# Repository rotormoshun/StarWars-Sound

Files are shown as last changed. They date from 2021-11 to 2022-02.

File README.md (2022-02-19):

# star_wars_arcade_sound_pcb
The source files for the reproduction of the 1983 Star Sars Arcade sound PCB. The PCB is designed with Kicad. This project is complete and the PCB is verified working!

# Folder Structure
* bom - Bill of materials for the sound PCB
* gerbers -The gerber files for the sound PCB
* images - Images used in the development on the sound PCB 
* pcb - The Kicad design files for the sound PCB

# PCB Specifications
* Layers: 2
* Dimensions: 293mm X 227mm
* Different PCB Design: 1
* PCB Thickness: 1.6mm
* Surface Finish: HASL
* Castellated Holes: No
* Copper Weight: 1oz.

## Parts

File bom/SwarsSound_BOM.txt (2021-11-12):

Part_ID                                                 QTY     DESC            Part_Num

C1,  C2,  C3,  C4,  C5,  C6,  C7,  C8,  C9,  C10,       41      0.1uf           Digikey 399-4454-1-ND
C11, C12, C16, C17, C18, C19, C20, C22, C23, C24,
C25, C26, C27, C28, C30, C37, C38, C40, C41, C42,
C43, C45, C54, C55, C59, C60, C61, C31, C32, C34,
C36

C46, C48, C49, C50, C56, C57, C58                       7       0.0027uf        Digikey 478-11573-1-ND
C13, C14, C15, C47, C53		                            5       100uf 50V       Digikey 1572-1309-ND
C29, C33, C35, C39                                      4       1000pf          Digikey 1216PHCT-ND
C44                                                     1       0.01uf          Digikey 399-4452-1-ND
C51                                                     1       0.47uf          Digikey 1572-1461-ND‎
C52                                                     1       10uf            Digikey 1572-1294-ND

DS1                                                     1       BLUE LED        Digikey VAOL-5701SBY4-ND

P2                                                      1       7 pin con       Digikey A19878-ND‎

Q1, Q2                                                  2       2N3906          Digikey 2N3906TAFSCT-ND
Q3, Q4                                                  2       2N3904          Digikey 2N3904TAFSCT-ND

R1,  R4,  R7,  R12, R15, R20, R22, R24, R26             9       1K              Digikey 1.0KQBK-ND
R2,  R3,  R5,  R6,  R10, R13, R17, R37                  8       10K             Digikey 10KQBK-ND
R30, R39, R40, R42, R46, R47                            6       12K             Digikey 12KQBK-ND
R21, R23, R50, R54, R55                                 5       47K             Digikey 47KQBK-ND
R48, R49, R52, R53                                      4       22K             Digikey 22KQBK-ND
R35, R51, R56                                           3       2.2K            Digikey 2.2KQBK-ND
R8,  R9,  R44                                           3       100             Digikey 100QBK-ND
R11, R14, R16                                           3       3.3K            Digikey 3.3KQBK-ND
R25, R27                                                2       82K             Digikey 82KQBK-ND
R33, R34                                                2       4.7K            Digikey 4.7KQBK-ND
R31, R32                                                2       560K            Digikey 560KQBK-ND
R18                                                     1       1.8K            Digikey 1.8KQBK-ND
R19, R28                                                2       100K            Digikey 100KQBK-ND
R29                                                     1       15K             Digikey 15KQBK-ND
R36                                                     1       15              Digikey 15QBK-ND
R38                                                     1       470             Digikey 470QBK-ND
R41                                                     1       68K             Digikey 68KQBK-ND
R43                                                     1       1.5K            Digikey 1.5KQBK-ND
R45                                                     1       470K            Digikey 470KQBK-ND

TP1,  TP2, TP3, TP4, TP5, TP6, TP7, TP8, TP9, TP10      12      Test Point      Digikey WM6456-ND
TP11, TP12

D-2, D-3, D-4, D-5                                      4       POKEY           Ebay
B-2, C-3, C-4                                           3       TL084           Digikey 296-1782-5-ND‎
H-1, J/K-1                                              2       2764            Jameco 2303119
F-3, F-5                                                2       LS161           Digikey 296-1646-5-ND
J-2, J-3                                                2       LS139           Digikey 296-1640-5-ND
J-5, K-5                                                2       LS374           Jameco 47634
C/D-1                                                   1       TMS-5220        Ebay
F/H-1                                                   1       6116-2K-RAM     Jameco 242675
F/H-5                                                   1       LS125           Jameco 46501
E-1                                                     1       PIA             Ebay
F-2                                                     1       CD4069/74C04    Jameco 13231
A-3                                                     1       NE556           Jameco 904114
B-3                                                     1       R5106           Ebay
H-2                                                     1       LS04            Jameco 46316
H-3                                                     1       LS00            Jameco 46252
H-5                                                     1       LS74            Jameco 48004
K-3                                                     1       6809E           Ebay

IC Sockets
-------------------
8  pin     1
14 pin     9
16-pin     4
20-pin     2
24-pin     1
28-pin     3
40-pin     6

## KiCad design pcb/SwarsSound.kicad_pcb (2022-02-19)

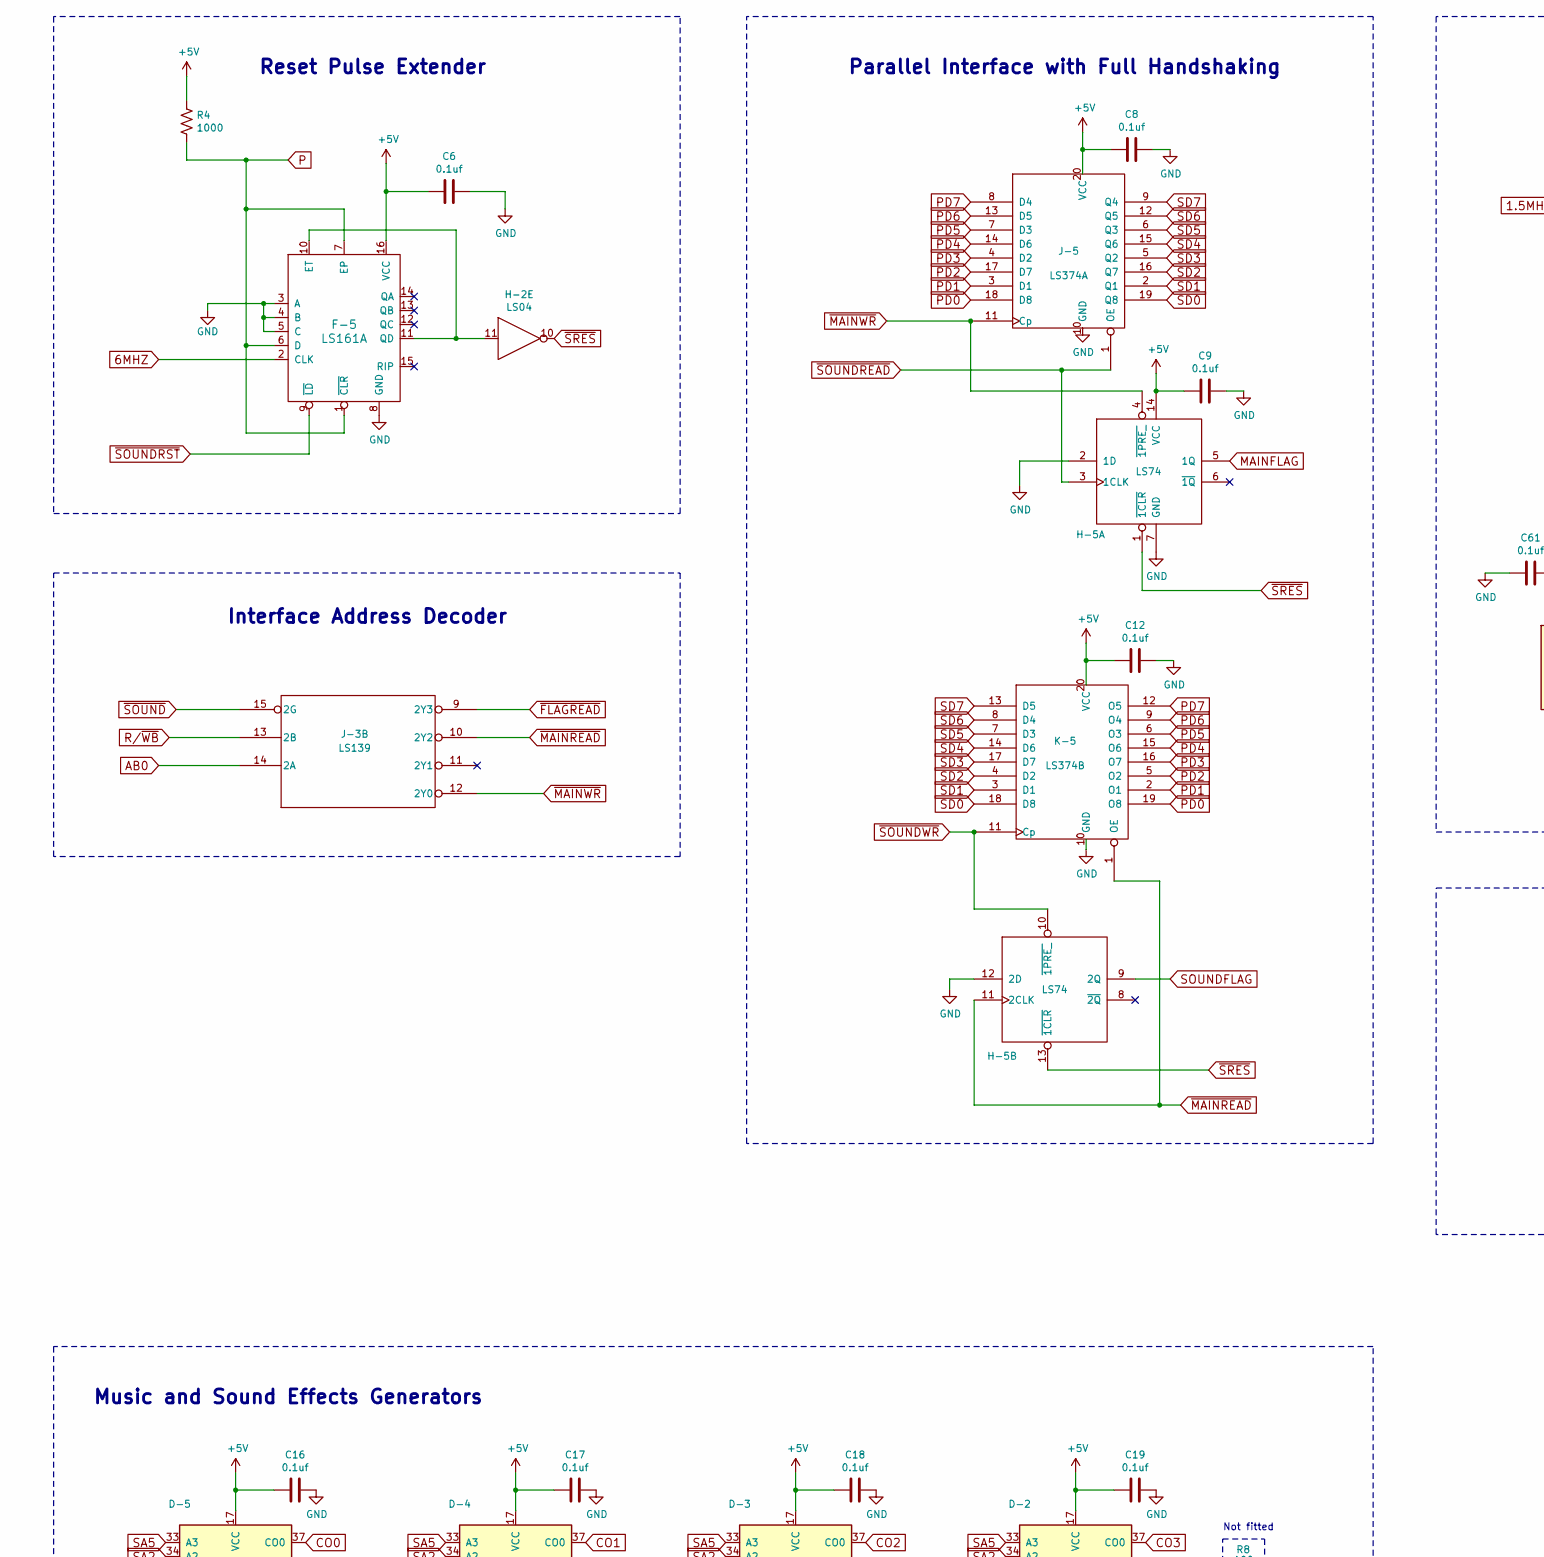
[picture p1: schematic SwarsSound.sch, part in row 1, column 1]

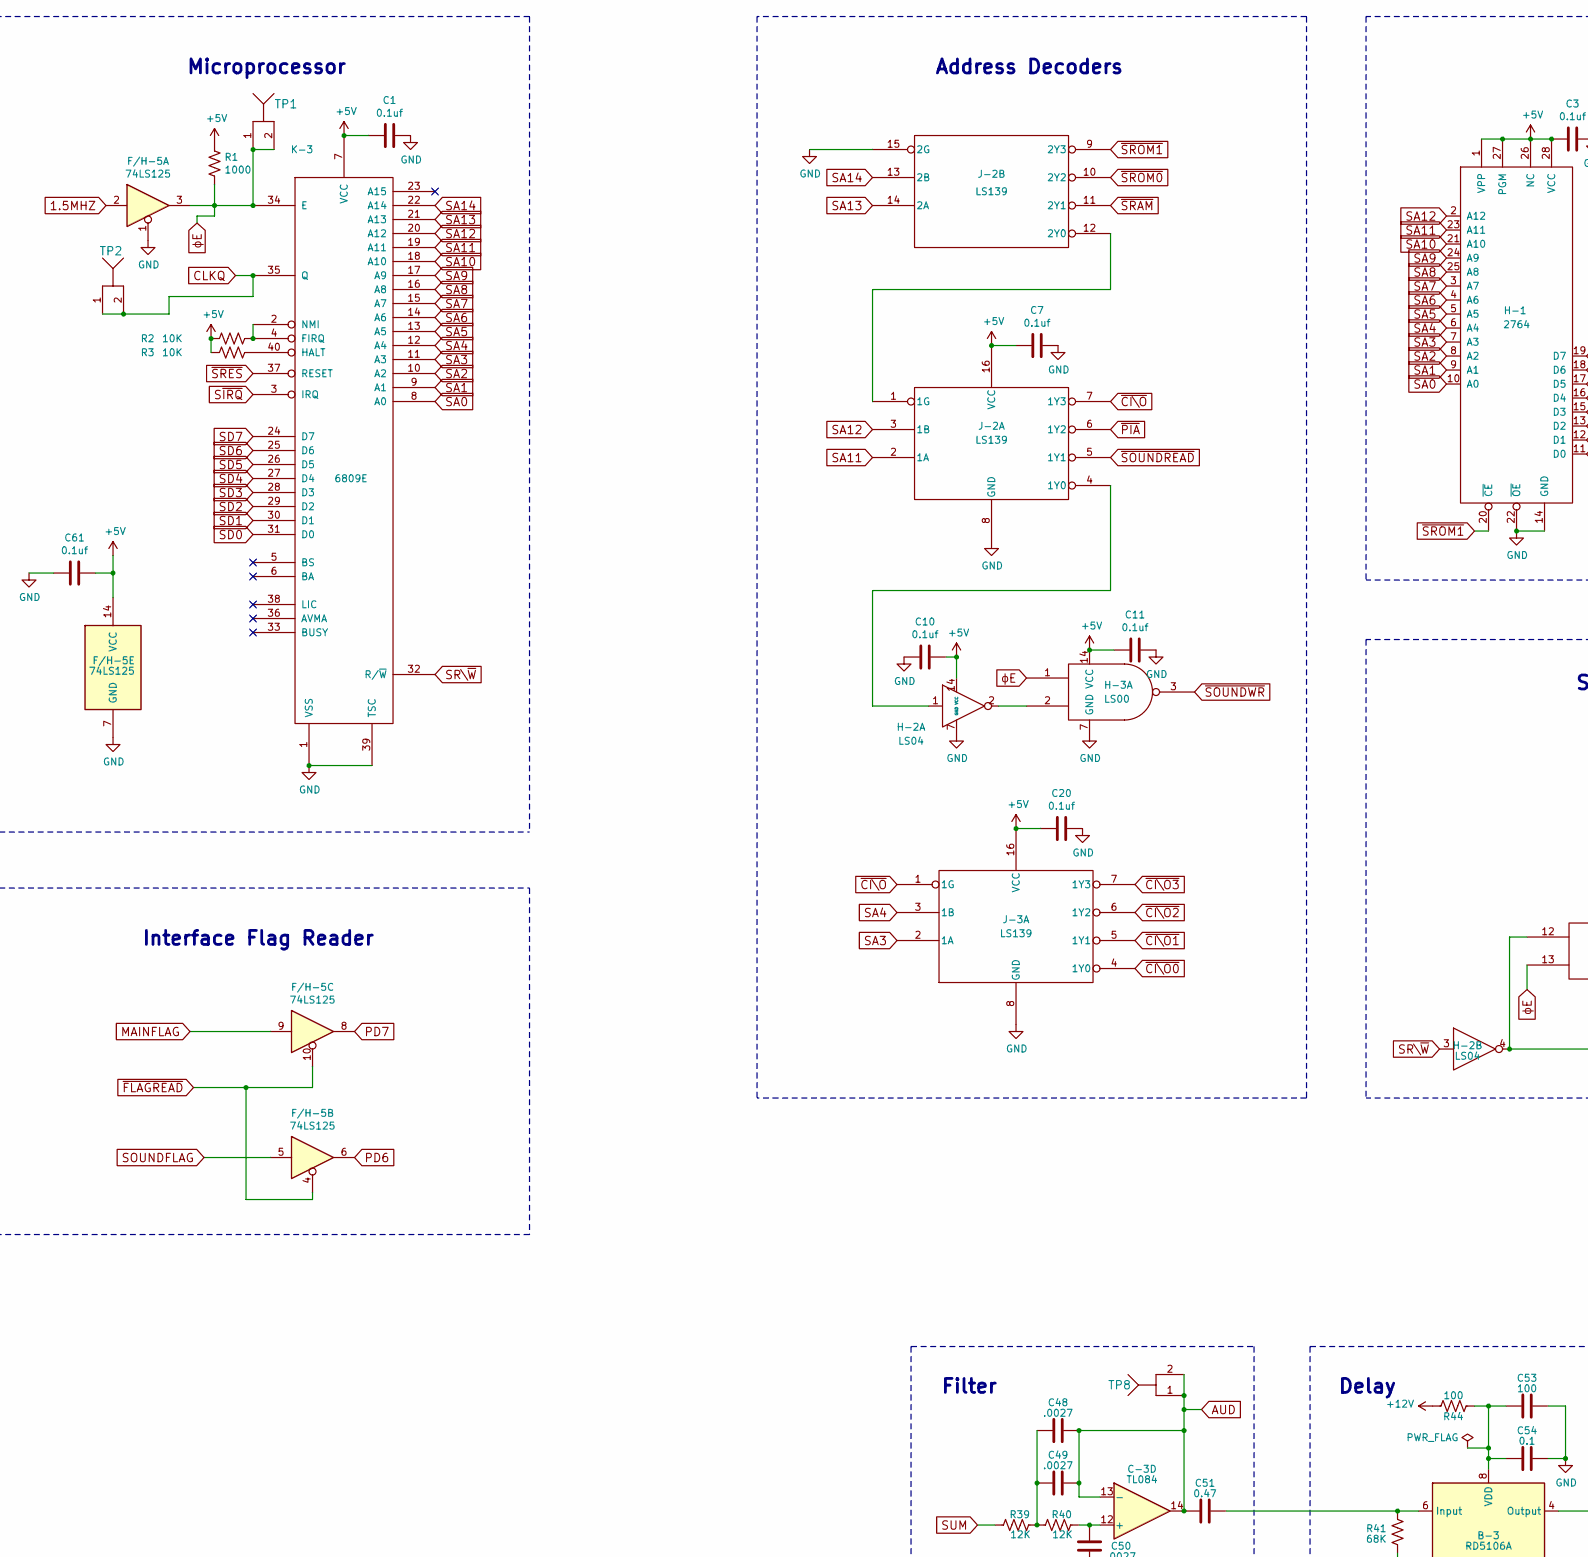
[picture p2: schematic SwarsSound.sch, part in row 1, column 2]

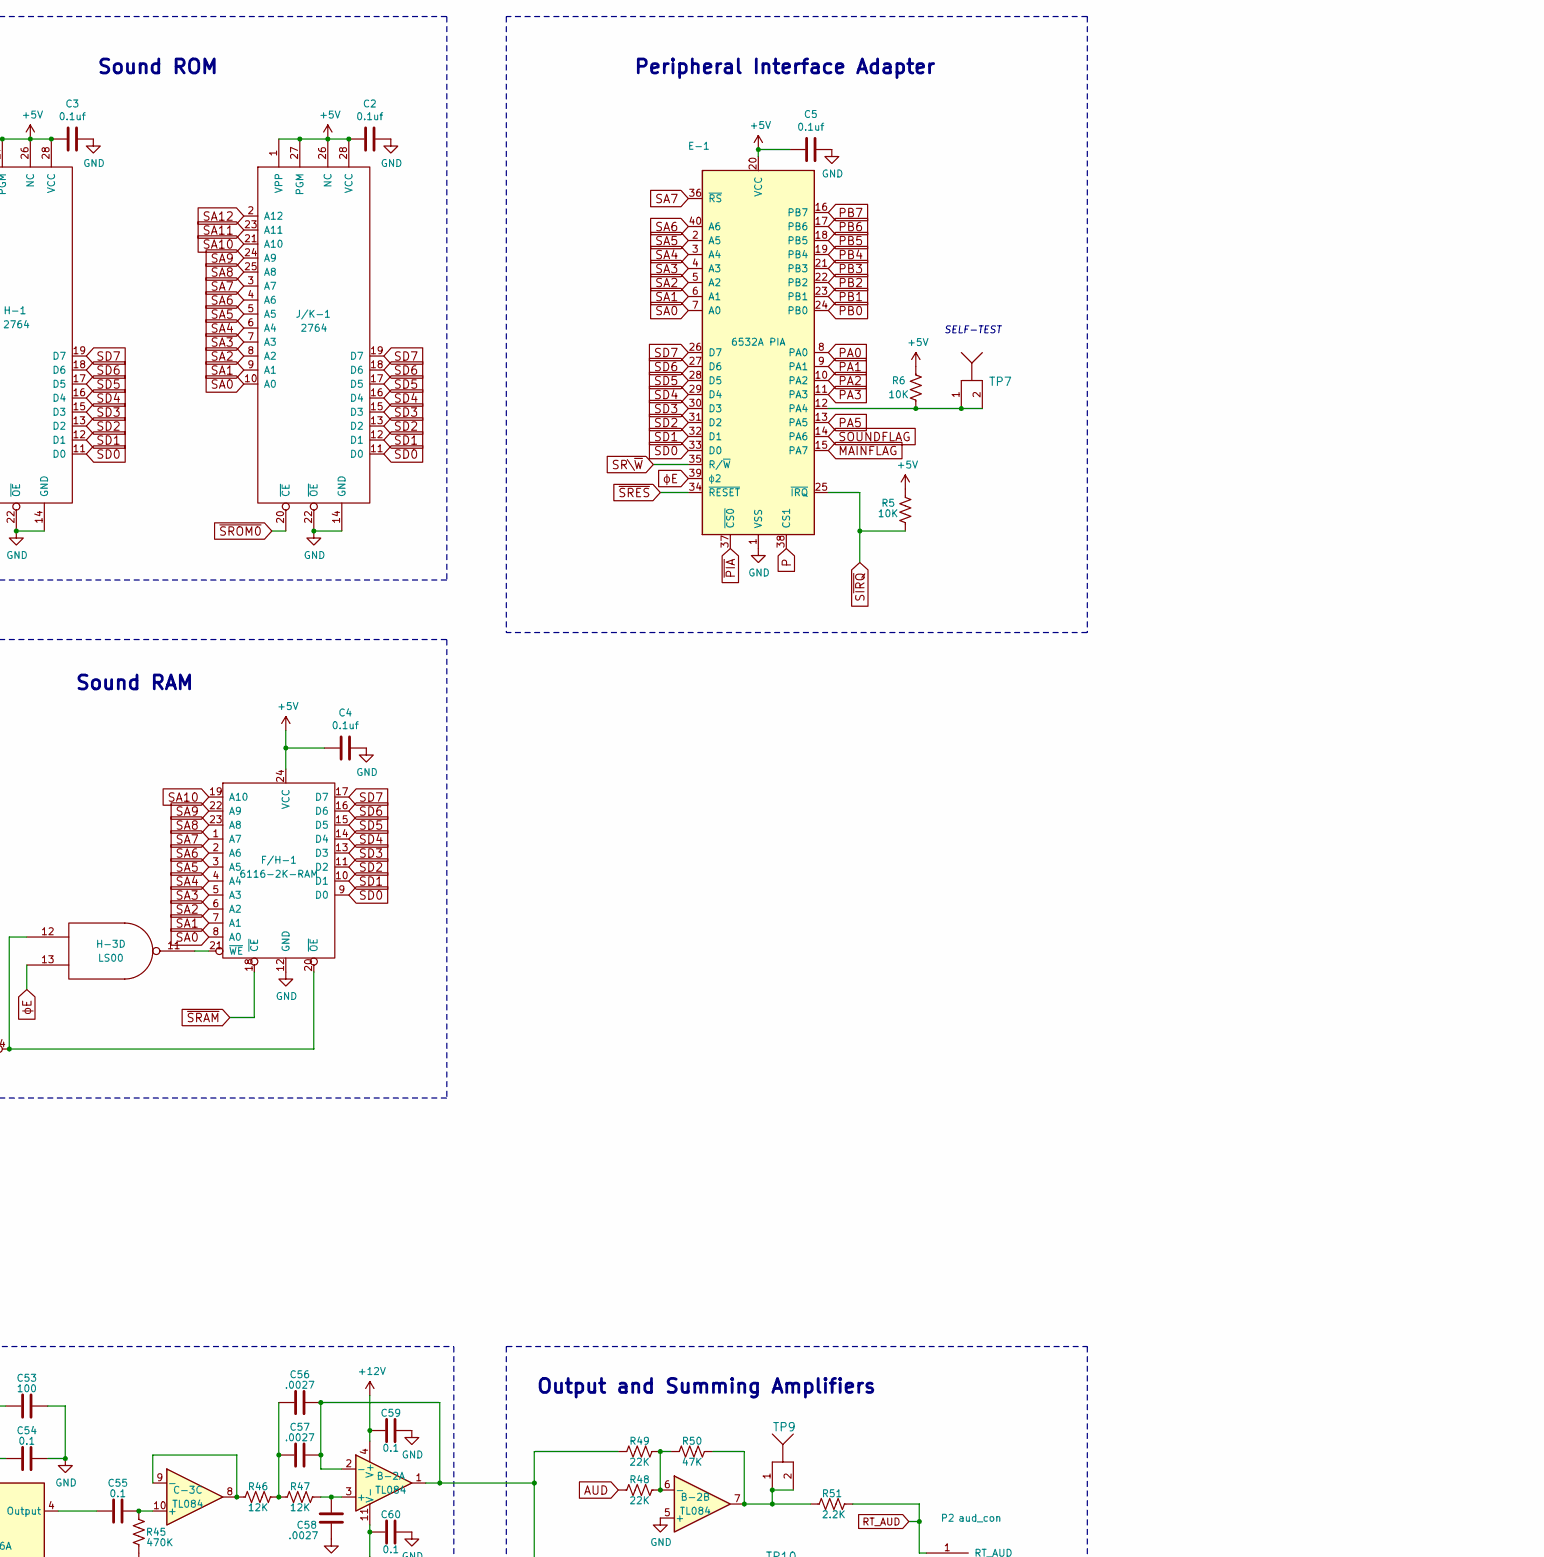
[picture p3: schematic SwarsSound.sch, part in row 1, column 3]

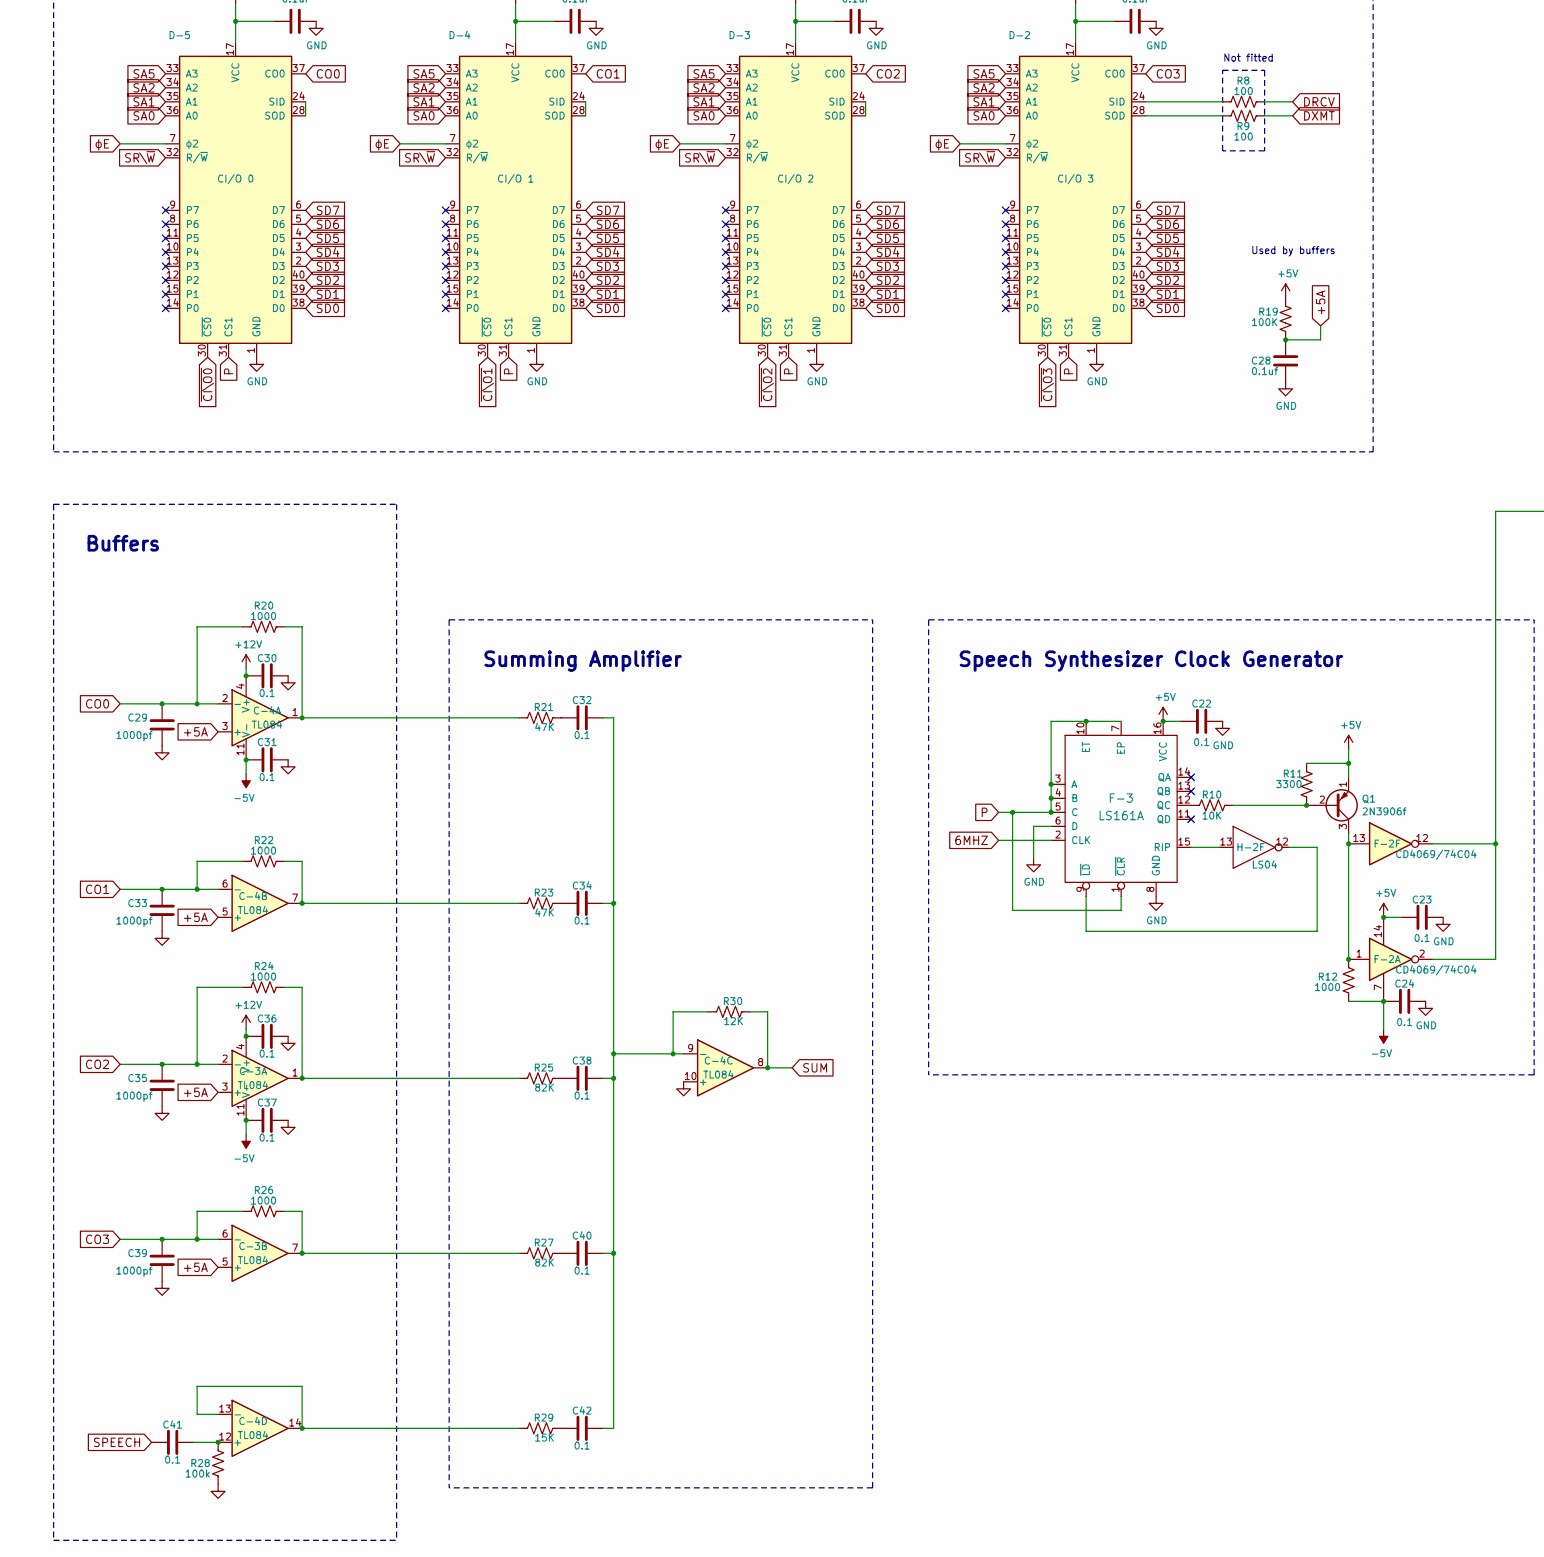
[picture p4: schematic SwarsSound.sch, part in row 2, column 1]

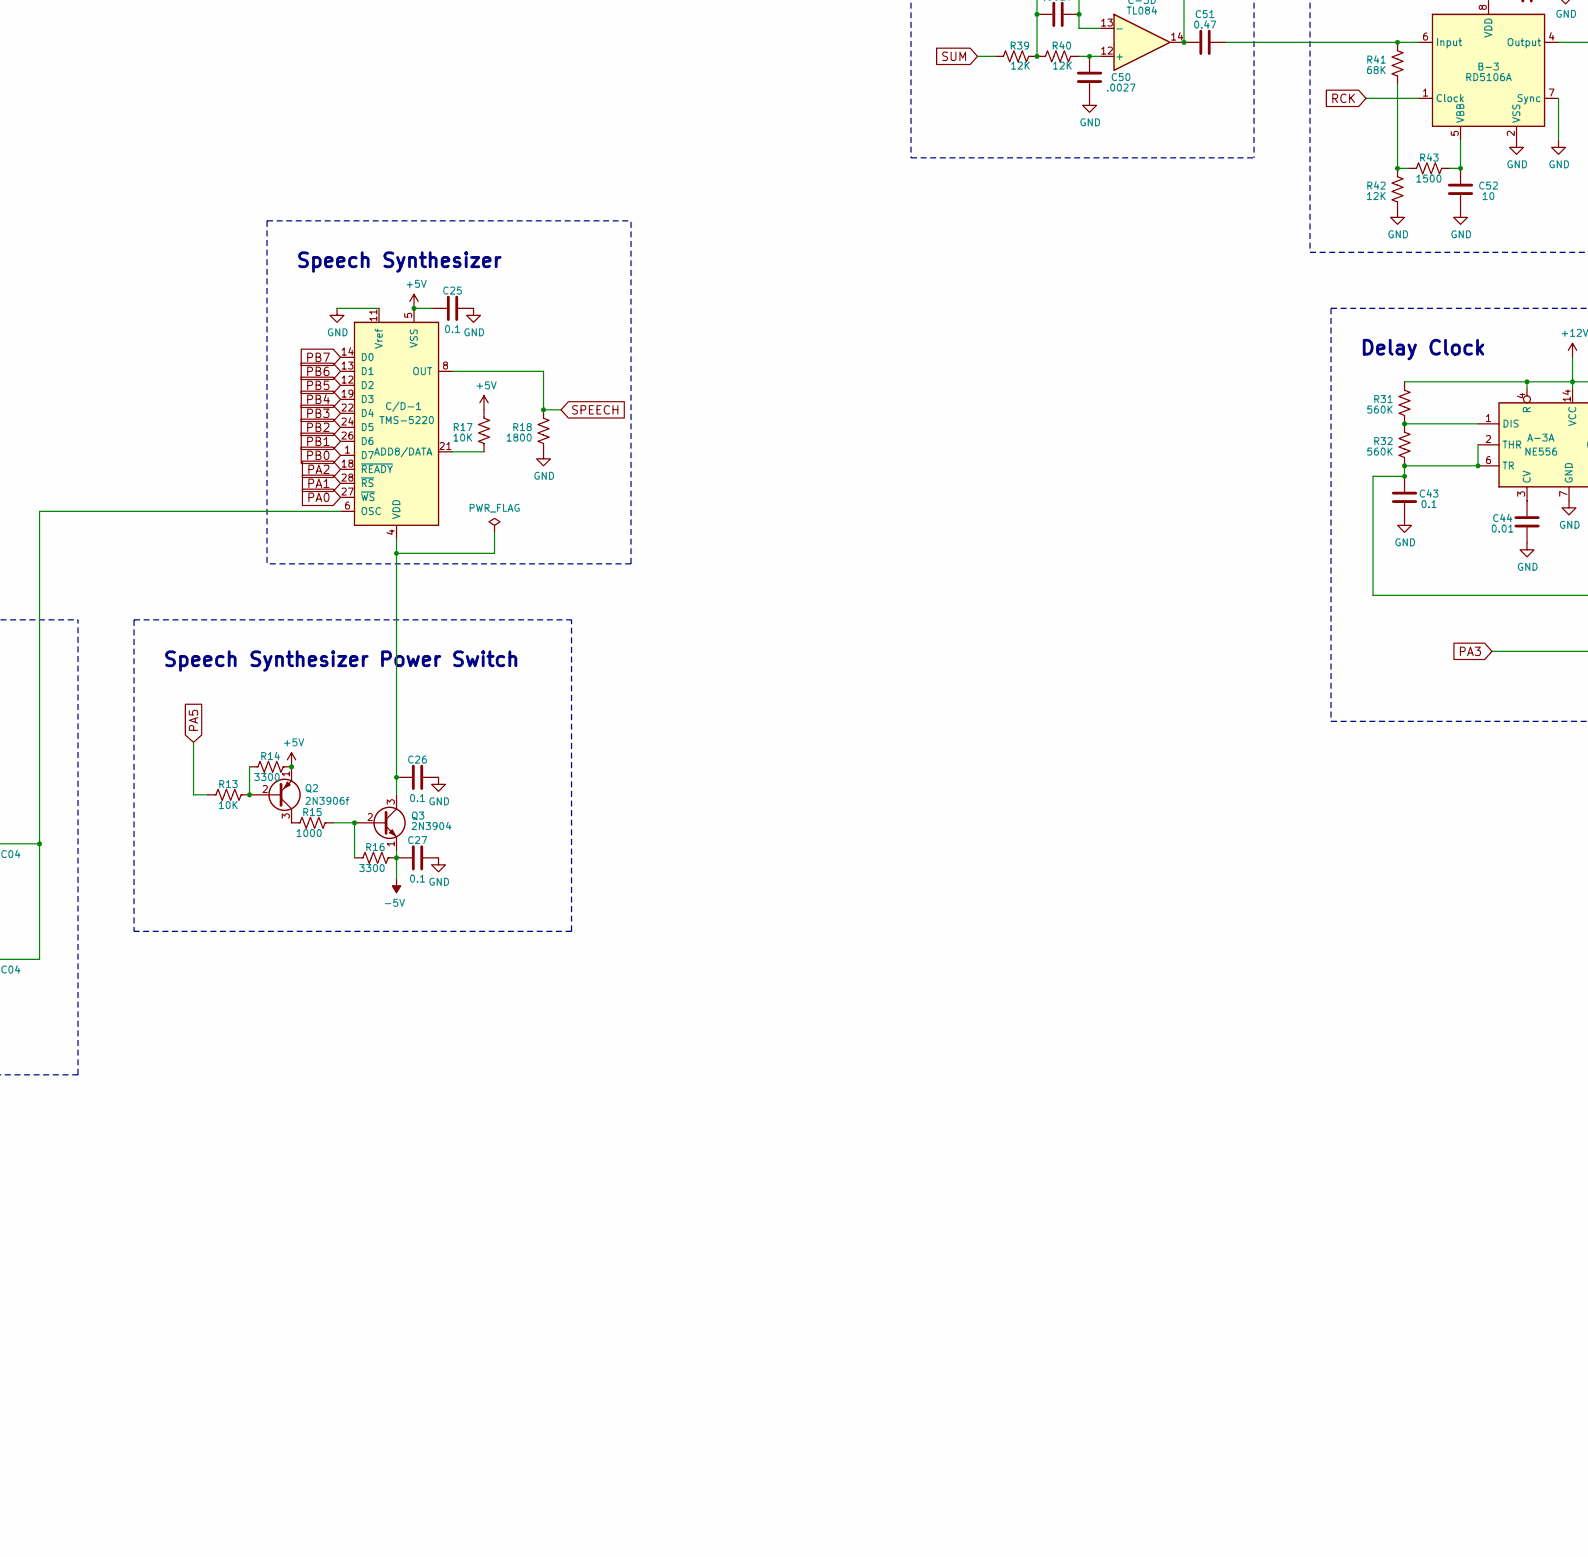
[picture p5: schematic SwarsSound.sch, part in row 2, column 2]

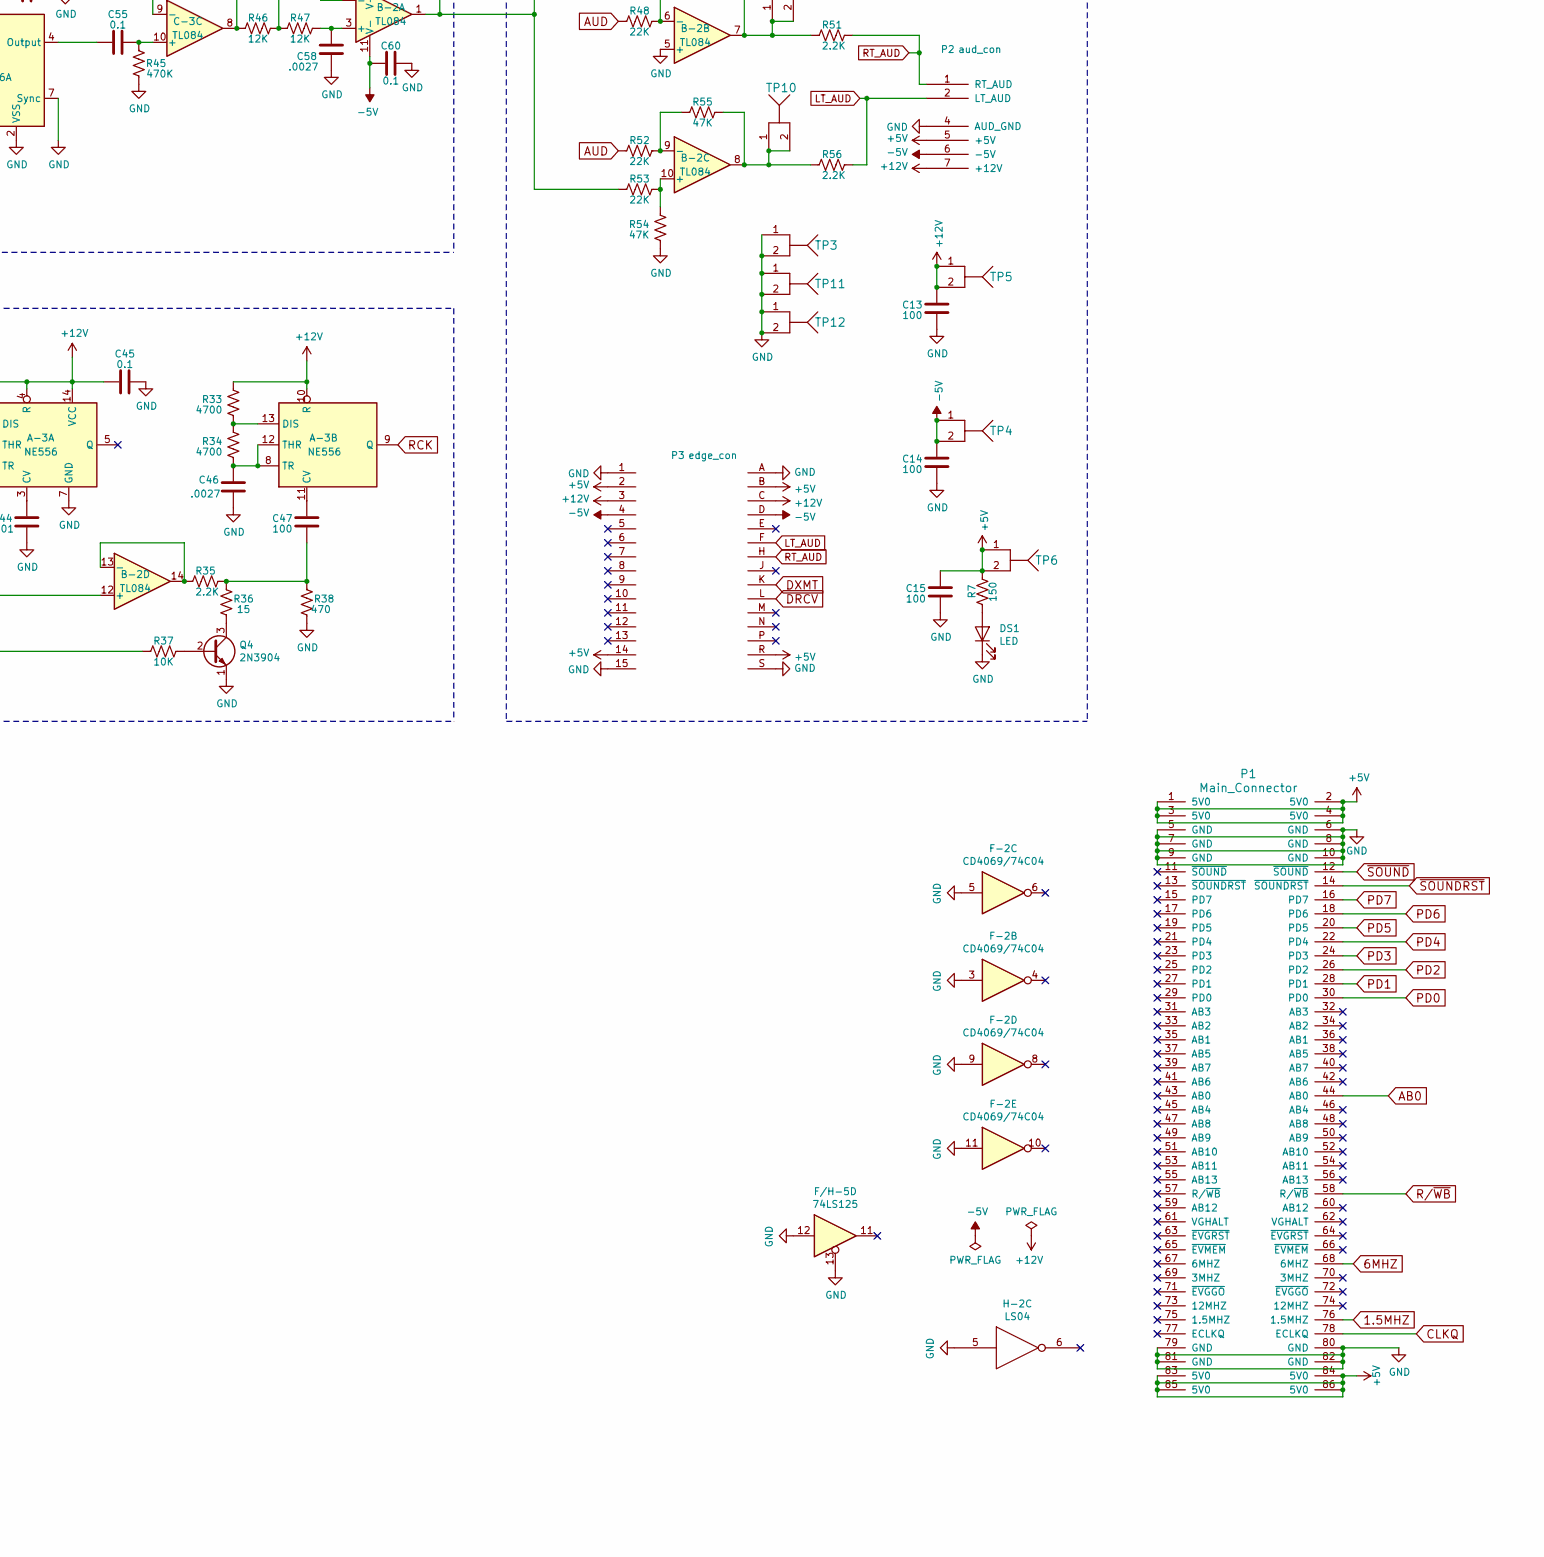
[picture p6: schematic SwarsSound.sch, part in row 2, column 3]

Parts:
A-3: NE556; DIP14
B-2: TL084; DIP14
B-3: RD5106A; DIP8
C1, C2, C3, C4, C5, C6, C7, C8, C9, C10, C11, C12, C16, C17, C18, C19, C20, C28, C61: 0.1uf; GenericComp
C13, C14: 100; CapElec3
C15, C47, C53: 100; CapElec2
C22, C23, C24, C25, C26, C27, C30, C31, C32, C34, C36, C37, C38, C40, C41, C42, C43, C45, C54, C55, C59, C60: 0.1; GenericComp
C29, C33, C35, C39: 1000pf; GenericComp
C44: 0.01; GenericComp
C46, C48, C49, C50, C56, C57, C58: .0027; GenericComp
C51: 0.47; CapElec2
C52: 10; CapElec2
C-3, C-4: TL084; DIP14
C/D-1: TMS-5220; DIP28
D-2: CI/O 3; DDIP40
D-3: CI/O 2; DDIP40
D-4: CI/O 1; DDIP40
D-5: CI/O 0; DDIP40
DS1: LED
E-1: 6532A PIA; DDIP40
F-2: CD4069/74C04; DIP14
F-3, F-5: LS161A; DIP16
F/H-1: 6116-2K-RAM; DDIP24
F/H-5: 74LS125; DIP14
H-1: 2764; DIP28
H-2: LS04; DIP14
H-3: LS00; DIP14
H-5: LS74; DIP14
J-2, J-3: LS139; DIP16
J-5: LS374A; DIP20
J/K-1: 2764; DIP28
K-3: 6809E; DDIP40
K-5: LS374B; DIP20
P1: Main_Connector; J17
P2: aud_con; Aud_Con_7
P3: edge_con; J20
Q1, Q2: 2N3906f; GenericTrans
Q3, Q4: 2N3904; GenericTrans
R1, R4, R12, R15, R20, R22, R24, R26: 1000; GenericComp
R2, R3, R5, R6, R10, R13, R17, R37: 10K; GenericComp
R7: 150; GenericComp
R8, R9, R44: 100; GenericComp
R11, R14, R16: 3300; GenericComp
R18: 1800; GenericComp
R19: 100K; GenericComp
R21, R23, R50, R54, R55: 47K; GenericComp
R25, R27: 82K; GenericComp
R28: 100k; GenericComp
R29: 15K; GenericComp
R30, R39, R40, R42, R46, R47: 12K; GenericComp
R31, R32: 560K; GenericComp
R33, R34: 4700; GenericComp
R35, R51, R56: 2.2K; GenericComp
R36: 15; GenericComp
R38: 470; GenericComp
R41: 68K; GenericComp
R43: 1500; GenericComp
R45: 470K; GenericComp
R48, R49, R52, R53: 22K; GenericComp
TP1, TP2, TP3, TP4, TP5, TP6, TP7, TP8, TP9, TP10, TP11, TP12: TP; TEST_POINT

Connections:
1.5MHZ: F/H-5.2, P1.76 (1.5MHZ)
6MHZ: F-3.2 (CLK), F-5.2 (CLK), P1.68 (6MHZ)
+5A: C28.2, C-3.3 (+), C-3.5 (+), C-4.3 (+), C-4.5 (+), R19.2
+5V: C1.2, C2.2, C3.2, C4.2, C5.2, C6.2, C7.2, C8.2, C9.2, C10.1, C11.2, C12.2, C15.2, C16.2, C17.2, C18.2, C19.2, C20.2, C22.1, C23.1, C25.1, C61.1, C/D-1.5 (VSS), D-2.17 (VCC), D-3.17 (VCC), D-4.17 (VCC), D-5.17 (VCC), E-1.20 (VCC), F-2.14, F-3.16 (VCC), F-5.16 (VCC), F/H-1.24 (VCC), F/H-5.14 (VCC), H-1.1 (VPP), H-1.26 (NC), H-1.27 (PGM), H-1.28 (VCC), H-2.14 (VCC), H-3.14 (VCC), H-5.14 (VCC), J-2.16 (VCC), J-3.16 (VCC), J-5.20 (VCC), J/K-1.1 (VPP), J/K-1.26 (NC), J/K-1.27 (PGM), J/K-1.28 (VCC), K-3.7 (VCC), K-5.20 (VCC), P1.1 (5V0), P1.2 (5V0), P1.3 (5V0), P1.4 (5V0), P1.83 (5V0), P1.84 (5V0), P1.85 (5V0), P1.86 (5V0), P2.5 (+5V), P3.2, P3.14, P3.B, P3.R, Q1.1, Q2.1, R1.1, R2.1, R3.1, R4.1, R5.1, R6.1, R7.1, R11.1, R14.2, R17.2, R19.1, TP6.1, TP6.2
+12V: A-3.4 (R), A-3.10 (R), A-3.14 (VCC), B-2.4 (V+), C13.2, C30.1, C36.1, C45.1, C59.1, C-3.4 (V+), C-4.4 (V+), P2.7 (+12V), P3.3, P3.C, R31.2, R33.2, R44.1, TP5.1, TP5.2
-5V: B-2.11 (V-), C14.2, C24.1, C27.1, C31.1, C37.1, C60.1, C-3.11 (V-), C-4.11 (V-), F-2.7, P2.6 (-5V), P3.4, P3.D, Q3.1 (E), R12.2, R16.2, TP4.1, TP4.2
AB0: J-3.14 (2A), P1.44 (AB0)
AUD: C48.2, C49.2, C51.1, C-3.13 (-), C-3.14, R48.2, R52.2, TP8.1, TP8.2
CLKQ: K-3.35 (Q), P1.78 (ECLKQ), TP2.1, TP2.2
CO0: C29.1, C-4.2 (-), D-5.37 (CO0), R20.2
CO1: C33.1, C-4.6 (-), D-4.37 (CO0), R22.2
CO2: C35.1, C-3.2 (-), D-3.37 (CO0), R24.2
CO3: C39.1, C-3.6 (-), D-2.37 (CO0), R26.2
DRCV: P3.L, R8.2
DXMT: P3.K, R9.2
GND: A-3.7 (GND), B-2.5 (+), B-3.2 (VSS), B-3.7 (Sync), C1.1, C2.1, C3.1, C4.1, C5.1, C6.1, C7.1, C8.1, C9.1, C10.2, C11.1, C12.1, C13.1, C14.1, C15.1, C16.1, C17.1, C18.1, C19.1, C20.1, C22.2, C23.2, C24.2, C25.2, C26.2, C27.2, C28.1, C29.2, C30.2, C31.2, C33.2, C35.2, C36.2, C37.2, C39.2, C43.1, C44.1, C45.2, C46.1, C50.1, C52.1, C53.2, C54.2, C58.1, C59.2, C60.2, C61.2, C-4.10 (+), C/D-1.11 (Vref), D-2.1 (GND), D-3.1 (GND), D-4.1 (GND), D-5.1 (GND), DS1.1 (K), E-1.1 (VSS), F-2.3, F-2.5, F-2.9, F-2.11, F-3.6 (D), F-3.8 (GND), F-5.3 (A), F-5.4 (B), F-5.5 (C), F-5.8 (GND), F/H-1.12 (GND), F/H-5.1, F/H-5.7 (GND), F/H-5.12, F/H-5.13, H-1.14 (GND), H-1.22 (~OE), H-2.5, H-2.7 (GND), H-3.7 (GND), H-5.2 (1D), H-5.7 (GND), H-5.12 (2D), J-2.8 (GND), J-2.15 (2G), J-3.8 (GND), J-5.10 (GND), J/K-1.14 (GND), J/K-1.22 (~OE), K-3.1 (VSS), K-3.39 (TSC), K-5.10 (GND), P1.5 (GND), P1.6 (GND), P1.7 (GND), P1.8 (GND), P1.9 (GND), P1.10 (GND), P1.79 (GND), P1.80 (GND), P1.81 (GND), P1.82 (GND), P2.4 (AUD_GND), P3.1, P3.15, P3.A, P3.S, Q4.1 (E), R18.1, R28.1, R38.1, R42.1, R45.1, R54.1, TP3.1, TP3.2, TP11.1, TP11.2, TP12.1, TP12.2
LT_AUD: P2.2 (LT_AUD), P3.F, R56.1
MAINFLAG: E-1.15 (PA7), F/H-5.9, H-5.5 (1Q)
unnamed: A-3.1 (DIS), R31.1, R32.2
unnamed: A-3.2 (THR), A-3.6 (TR), B-2.12 (+), C43.2, R32.1
unnamed: A-3.3 (CV), C44.2
unnamed: A-3.11 (CV), C47.2
unnamed: A-3.8 (TR), A-3.12 (THR), C46.2, R34.1
unnamed: A-3.13 (DIS), R33.1, R34.2
unnamed: B-2.1, B-2.2 (-), C56.2, C57.2, R49.2, R53.2
unnamed: B-2.3 (+), C58.2, R47.1
unnamed: B-2.6 (-), R48.1, R49.1, R50.2
unnamed: B-2.7, R50.1, R51.2, TP9.1, TP9.2
unnamed: B-2.8, R55.1, R56.2, TP10.1, TP10.2
unnamed: B-2.9 (-), R52.1, R55.2
unnamed: B-2.10 (+), R53.1, R54.2
unnamed: B-2.13 (-), B-2.14, R35.2
unnamed: B-3.4 (Output), C55.1
unnamed: B-3.5 (VBB), C52.2, R43.1
unnamed: B-3.6 (Input), C51.2, R41.2
unnamed: B-3.8 (VDD), C53.1, C54.1, R44.2
unnamed: C32.1, R21.1
unnamed: C34.1, R23.1
unnamed: C38.1, R25.1
unnamed: C40.1, R27.1
unnamed: C42.1, R29.1
unnamed: C47.1, R35.1, R36.2, R38.2
unnamed: C48.1, C49.1, R39.1, R40.2
unnamed: C56.1, C57.1, R46.1, R47.2
unnamed: C-3.1, R24.1, R25.2
unnamed: C-3.7, R26.1, R27.2
unnamed: C-3.8, C-3.9 (-), R46.2
unnamed: C55.2, C-3.10 (+), R45.2
unnamed: C50.2, C-3.12 (+), R40.1
unnamed: C-4.1, R20.1, R21.2
unnamed: C-4.7, R22.1, R23.2
unnamed: C32.2, C34.2, C38.2, C40.2, C42.2, C-4.9 (-), R30.2
unnamed: C41.1, C-4.12 (+), R28.2
unnamed: C-4.13 (-), C-4.14, R29.2
unnamed: C26.1, C/D-1.4 (VDD), Q3.3 (C)
unnamed: C/D-1.6 (OSC), F-2.2, F-2.12
unnamed: C/D-1.21 (ADD8/DATA), R17.1
unnamed: D-2.24 (SID), R8.1
unnamed: D-2.28 (SOD), R9.1
unnamed: D-3.24 (SID), D-3.28 (SOD)
unnamed: D-4.24 (SID), D-4.28 (SOD)
unnamed: D-5.24 (SID), D-5.28 (SOD)
unnamed: DS1.2 (A), R7.2
unnamed: E-1.12 (PA4), R6.2, TP7.1, TP7.2
unnamed: F-2.1, F-2.13, Q1.3, R12.1
unnamed: F-3.9 (~LD), H-2.12
unnamed: F-3.12 (QC), R10.1
unnamed: F-3.15 (RIP), H-2.13
unnamed: F-5.10 (ET), F-5.11 (QD), H-2.11
unnamed: F/H-1.20 (~OE), H-2.4, H-3.12
unnamed: F/H-1.21 (~WE), H-3.11
unnamed: H-2.1, J-2.4 (1Y0)
unnamed: H-2.2, H-3.2
unnamed: J-2.1 (1G), J-2.12 (2Y0)
unnamed: K-3.2 (NMI), K-3.4 (FIRQ), R2.2
unnamed: K-3.40 (HALT), R3.2
unnamed: Q1.2, R10.2, R11.2
unnamed: Q2.2, R13.2, R14.1
unnamed: Q2.3, R15.1
unnamed: Q3.2 (B), R15.2, R16.1
unnamed: Q4.2 (B), R37.1
unnamed: Q4.3 (C), R36.1
unnamed: R41.1, R42.2, R43.2
P: D-2.31 (CS1), D-3.31 (CS1), D-4.31 (CS1), D-5.31 (CS1), E-1.38 (CS1), F-3.1 (~CLR), F-3.3 (A), F-3.4 (B), F-3.5 (C), F-3.7 (EP), F-3.10 (ET), F-5.1 (~CLR), F-5.6 (D), F-5.7 (EP), R4.2
PA0: C/D-1.27 (~WS), E-1.8 (PA0)
PA1: C/D-1.28 (~RS), E-1.9 (PA1)
PA2: C/D-1.18 (~READY), E-1.10 (PA2)
PA3: E-1.11 (PA3), R37.2
PA5: E-1.13 (PA5), R13.1
PB0: C/D-1.1 (D7), E-1.24 (PB0)
PB1: C/D-1.26 (D6), E-1.23 (PB1)
PB2: C/D-1.24 (D5), E-1.22 (PB2)
PB3: C/D-1.22 (D4), E-1.21 (PB3)
PB4: C/D-1.19 (D3), E-1.19 (PB4)
PB5: C/D-1.12 (D2), E-1.18 (PB5)
PB6: C/D-1.13 (D1), E-1.17 (PB6)
PB7: C/D-1.14 (D0), E-1.16 (PB7)
PD0: J-5.18 (D8), K-5.19 (O8), P1.30 (PD0)
PD1: J-5.3 (D1), K-5.2 (O1), P1.28 (PD1)
PD2: J-5.17 (D7), K-5.5 (O2), P1.26 (PD2)
PD3: J-5.4 (D2), K-5.16 (O7), P1.24 (PD3)
PD4: J-5.14 (D6), K-5.15 (O6), P1.22 (PD4)
PD5: J-5.7 (D3), K-5.6 (O3), P1.20 (PD5)
PD6: F/H-5.6, J-5.13 (D5), K-5.9 (O4), P1.18 (PD6)
PD7: F/H-5.8, J-5.8 (D4), K-5.12 (O5), P1.16 (PD7)
R/~WB: J-3.13 (2B), P1.58 (R/~WB)
RCK: A-3.9 (Q), B-3.1 (Clock)
RT_AUD: P2.1 (RT_AUD), P3.H, R51.1
SA0: D-2.36 (A0), D-3.36 (A0), D-4.36 (A0), D-5.36 (A0), E-1.7 (A0), F/H-1.8 (A0), H-1.10 (A0), J/K-1.10 (A0), K-3.8 (A0)
SA1: D-2.35 (A1), D-3.35 (A1), D-4.35 (A1), D-5.35 (A1), E-1.6 (A1), F/H-1.7 (A1), H-1.9 (A1), J/K-1.9 (A1), K-3.9 (A1)
SA2: D-2.34 (A2), D-3.34 (A2), D-4.34 (A2), D-5.34 (A2), E-1.5 (A2), F/H-1.6 (A2), H-1.8 (A2), J/K-1.8 (A2), K-3.10 (A2)
SA3: E-1.4 (A3), F/H-1.5 (A3), H-1.7 (A3), J-3.2 (1A), J/K-1.7 (A3), K-3.11 (A3)
SA4: E-1.3 (A4), F/H-1.4 (A4), H-1.6 (A4), J-3.3 (1B), J/K-1.6 (A4), K-3.12 (A4)
SA5: D-2.33 (A3), D-3.33 (A3), D-4.33 (A3), D-5.33 (A3), E-1.2 (A5), F/H-1.3 (A5), H-1.5 (A5), J/K-1.5 (A5), K-3.13 (A5)
SA6: E-1.40 (A6), F/H-1.2 (A6), H-1.4 (A6), J/K-1.4 (A6), K-3.14 (A6)
SA7: E-1.36 (~RS), F/H-1.1 (A7), H-1.3 (A7), J/K-1.3 (A7), K-3.15 (A7)
SA8: F/H-1.23 (A8), H-1.25 (A8), J/K-1.25 (A8), K-3.16 (A8)
SA9: F/H-1.22 (A9), H-1.24 (A9), J/K-1.24 (A9), K-3.17 (A9)
SA10: F/H-1.19 (A10), H-1.21 (A10), J/K-1.21 (A10), K-3.18 (A10)
SA11: H-1.23 (A11), J-2.2 (1A), J/K-1.23 (A11), K-3.19 (A11)
SA12: H-1.2 (A12), J-2.3 (1B), J/K-1.2 (A12), K-3.20 (A12)
SA13: J-2.14 (2A), K-3.21 (A13)
SA14: J-2.13 (2B), K-3.22 (A14)
SD0: D-2.38 (D0), D-3.38 (D0), D-4.38 (D0), D-5.38 (D0), E-1.33 (D0), F/H-1.9 (D0), H-1.11 (D0), J-5.19 (Q8), J/K-1.11 (D0), K-3.31 (D0), K-5.18 (D8)
SD1: D-2.39 (D1), D-3.39 (D1), D-4.39 (D1), D-5.39 (D1), E-1.32 (D1), F/H-1.10 (D1), H-1.12 (D1), J-5.2 (Q1), J/K-1.12 (D1), K-3.30 (D1), K-5.3 (D1)
SD2: D-2.40 (D2), D-3.40 (D2), D-4.40 (D2), D-5.40 (D2), E-1.31 (D2), F/H-1.11 (D2), H-1.13 (D2), J-5.16 (Q7), J/K-1.13 (D2), K-3.29 (D2), K-5.4 (D2)
SD3: D-2.2 (D3), D-3.2 (D3), D-4.2 (D3), D-5.2 (D3), E-1.30 (D3), F/H-1.13 (D3), H-1.15 (D3), J-5.5 (Q2), J/K-1.15 (D3), K-3.28 (D3), K-5.17 (D7)
SD4: D-2.3 (D4), D-3.3 (D4), D-4.3 (D4), D-5.3 (D4), E-1.29 (D4), F/H-1.14 (D4), H-1.16 (D4), J-5.15 (Q6), J/K-1.16 (D4), K-3.27 (D4), K-5.14 (D6)
SD5: D-2.4 (D5), D-3.4 (D5), D-4.4 (D5), D-5.4 (D5), E-1.28 (D5), F/H-1.15 (D5), H-1.17 (D5), J-5.6 (Q3), J/K-1.17 (D5), K-3.26 (D5), K-5.7 (D3)
SD6: D-2.5 (D6), D-3.5 (D6), D-4.5 (D6), D-5.5 (D6), E-1.27 (D6), F/H-1.16 (D6), H-1.18 (D6), J-5.12 (Q5), J/K-1.18 (D6), K-3.25 (D6), K-5.8 (D4)
SD7: D-2.6 (D7), D-3.6 (D7), D-4.6 (D7), D-5.6 (D7), E-1.26 (D7), F/H-1.17 (D7), H-1.19 (D7), J-5.9 (Q4), J/K-1.19 (D7), K-3.24 (D7), K-5.13 (D5)
SOUNDFLAG: E-1.14 (PA6), F/H-5.5, H-5.9 (2Q)
SPEECH: C41.2, C/D-1.8 (OUT), R18.2
SR\~W: D-2.32 (R/~W), D-3.32 (R/~W), D-4.32 (R/~W), D-5.32 (R/~W), E-1.35 (R/~W), H-2.3, K-3.32 (R/~W)
SUM: C-4.8, R30.1, R39.2
S~IRQ: E-1.25 (~IRQ), K-3.3 (IRQ), R5.2
~CI\O: J-2.7 (1Y3), J-3.1 (1G)
~CI\O0: D-5.30 (~CS0), J-3.4 (1Y0)
~CI\O1: D-4.30 (~CS0), J-3.5 (1Y1)
~CI\O2: D-3.30 (~CS0), J-3.6 (1Y2)
~CI\O3: D-2.30 (~CS0), J-3.7 (1Y3)
~FLAGREAD: F/H-5.4, F/H-5.10, J-3.9 (2Y3)
~MAINREAD: H-5.11 (2CLK), J-3.10 (2Y2), K-5.1 (OE)
~MAINWR: H-5.4 (~1PRE_), J-3.12 (2Y0), J-5.11 (Cp)
~PIA: E-1.37 (~CS0), J-2.6 (1Y2)
~SOUND: J-3.15 (2G), P1.12 (~SOUND)
~SOUNDREAD: H-5.3 (1CLK), J-2.5 (1Y1), J-5.1 (OE)
~SOUNDRST: F-5.9 (~LD), P1.14 (~SOUNDRST)
~SOUNDWR: H-3.3, H-5.10 (~1PRE_), K-5.11 (Cp)
~SRAM: F/H-1.18 (~CE), J-2.11 (2Y1)
~SRES: E-1.34 (~RESET), H-2.10, H-5.1 (~1CLR), H-5.13 (~1CLR), K-3.37 (RESET)
~SROM0: J-2.10 (2Y2), J/K-1.20 (~CE)
~SROM1: H-1.20 (~CE), J-2.9 (2Y3)
ɸE: D-2.7 (ɸ2), D-3.7 (ɸ2), D-4.7 (ɸ2), D-5.7 (ɸ2), E-1.39 (ɸ2), F/H-5.3, H-3.1, H-3.13, K-3.34 (E), R1.2, TP1.1, TP1.2

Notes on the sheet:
Peripheral Interface Adapter
Filter
Delay
Output and Summing Amplifiers
Delay Clock
Sound RAM
Speech Synthesizer Clock Generator
Reset Pulse Extender
Interface Address Decoder
Parallel Interface with Full Handshaking
Microprocessor
Interface Flag Reader
Address Decoders
Sound ROM
Music and Sound Effects Generators
Used by buffers
SELF-TEST
Buffers
Summing Amplifier
Speech Synthesizer
Speech Synthesizer Power Switch
Not fitted

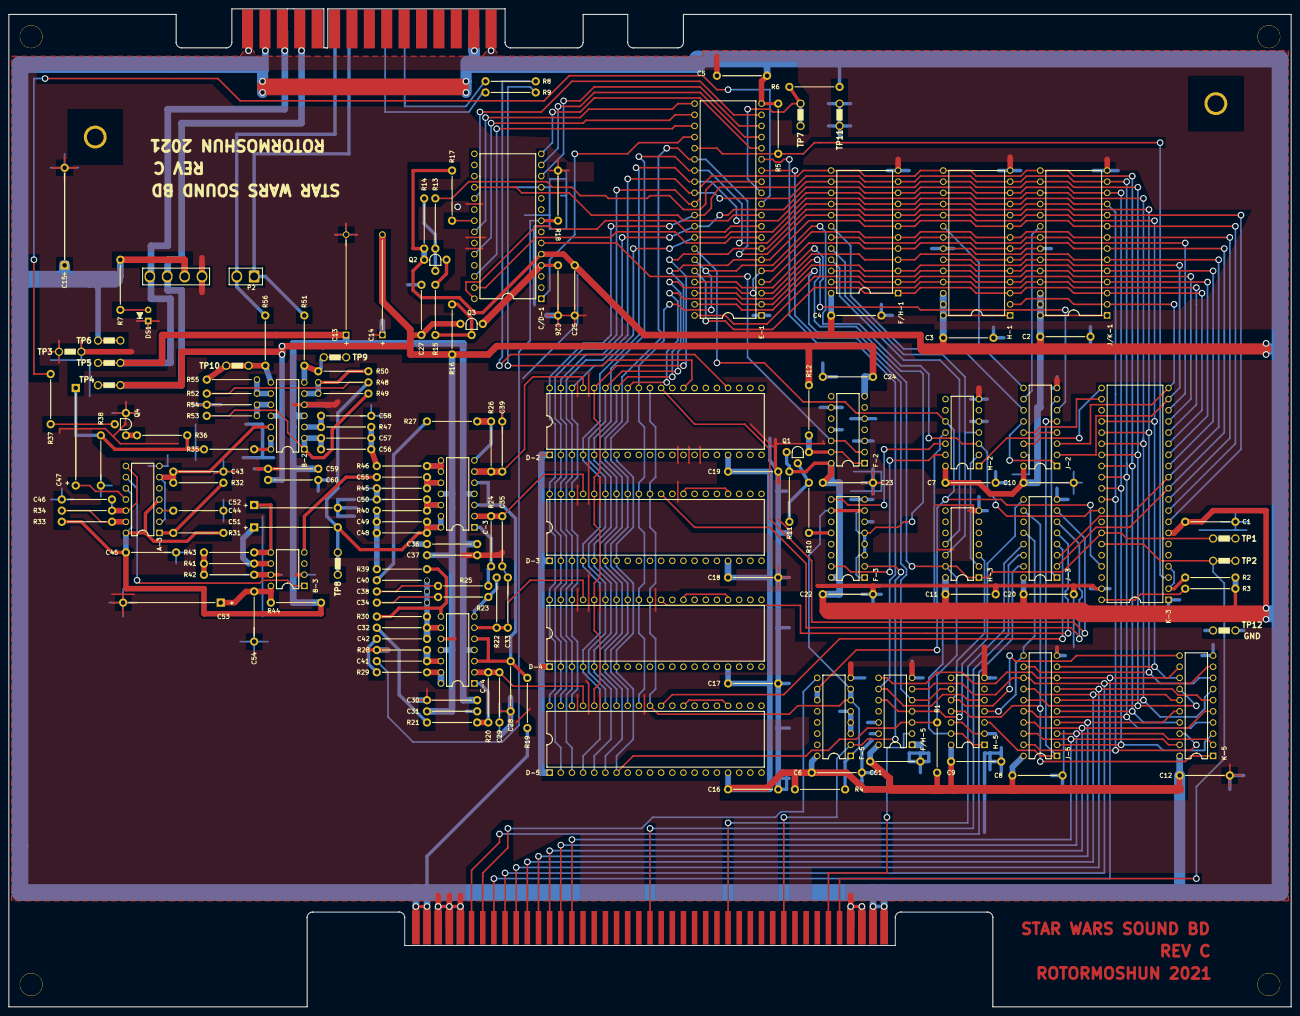
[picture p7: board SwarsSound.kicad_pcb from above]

Board: 2 copper layers, 292.1 x 227.3 mm, 162 parts (1 on the bottom side), 154 nets.

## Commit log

2021-06-28 Joint session
    Added footprints and plopped chips on nonexistent board.
    [SwarsSound.kicad_pcb, SwarsSound.sch]
2021-06-28 Moved a spot
    [SwarsSound.kicad_pcb]
2021-06-28 Began board layout
    [SwarsSound.kicad_pcb, SwarsSound.sch]
2021-06-29 Finished chip layout
    [SwarsSound.kicad_pcb, SwarsSound.sch]
2021-07-01 next push
    [SwarsSound.kicad_pcb, SwarsSound.sch]
2021-07-02 Added TPs and large caps
    [SwarsSound.kicad_pcb, SwarsSound.sch]
2021-07-02 right to left to C14 Placed
    [SwarsSound.kicad_pcb]
2021-07-03 All components placed
    [SwarsSound.kicad_pcb]
2021-07-03 Routed some traces
    Couldn't help myself
    [SwarsSound.kicad_pcb]
2021-07-04 Added some traces
    [SwarsSound.kicad_pcb]
2021-07-04 More traces 15 MM
    Make all traces 15MM instead of Default, choose from menu
    [SwarsSound.kicad_pcb]
2021-07-06 thickened POKEY traces
    made them too thin while learning
    [SwarsSound.kicad_pcb]
2021-07-06 ROM and RAM buses
    Not complete
    [SwarsSound.kicad_pcb]
2021-07-06 fixes
    fixed RAM (pin '28' -> 24) and finished RAM/ROM data bus.
    [SwarsSound.kicad_pcb, SwarsSound.sch]
2021-07-06 more traces
    [SwarsSound.kicad_pcb]
2021-07-09 more scan footprints
2021-07-10 More traces on top done
    [SwarsSound.kicad_pcb]
2021-07-11 More traces completed
    [SwarsSound.kicad_pcb]
2021-07-11 more traces on bottom completed
    [SwarsSound.kicad_pcb]
2021-07-14 Verified spacing and added some traces
    [SwarsSound.kicad_pcb, SwarsSound.sch]
2021-07-14 more traces done
    [SwarsSound.kicad_pcb]
2021-07-15 Modified some traces
    [SwarsSound.kicad_pcb, SwarsSound.sch]
2021-07-16 Even more traces
    [SwarsSound.kicad_pcb]
2021-07-17 Fixed some traces
    [SwarsSound.kicad_pcb]
2021-07-17 all traces done
    [SwarsSound.kicad_pcb]
2021-07-19 Completed the back of the PCB
    [SwarsSound.kicad_pcb, SwarsSound.sch]
2021-07-26 Finished top layer traces
    [SwarsSound.kicad_pcb, SwarsSound.sch]
2021-07-26 Added top layer
    [SwarsSound.kicad_pcb, SwarsSound.sch]
2021-07-27 Started the BOM
    [SwarsSound.kicad_pcb]
2021-07-27 Finished the top layer plane
    [SwarsSound.kicad_pcb]
2021-07-28 Silkscreen updated
    [SwarsSound.kicad_pcb]
2021-07-28 Finished PCB
    [SwarsSound.kicad_pcb]
2021-07-28 Added gerber files
    [SwarsSound-B_Cu.gbr, SwarsSound-B_Mask.gbr, SwarsSound-B_SilkS.gbr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]
2021-08-07 Board Tested and Working
    Board built, tested and working
2021-11-09 Updated BOM and test points
    [SwarsSound.kicad_pcb]
2021-11-09 Completed the BOM
    [SwarsSound.kicad_pcb]
2021-11-12 Changed R28 value from 1k to 100k in schematic and BOM
    [SwarsSound.kicad_pcb, SwarsSound.sch]
2022-02-19 Updated the file structure and added a readme file
    [SwarsSound-B_Cu.gbr, SwarsSound-B_Mask.gbr, SwarsSound-B_SilkS.gbr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]
